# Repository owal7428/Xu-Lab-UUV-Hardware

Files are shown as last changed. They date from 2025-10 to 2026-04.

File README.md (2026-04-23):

# Xu-Lab-UUV-Hardware
Hardware design for Xu Lab underwater modular robotic platform project.

Controller board: <br>
controller

Power board: <br>

power

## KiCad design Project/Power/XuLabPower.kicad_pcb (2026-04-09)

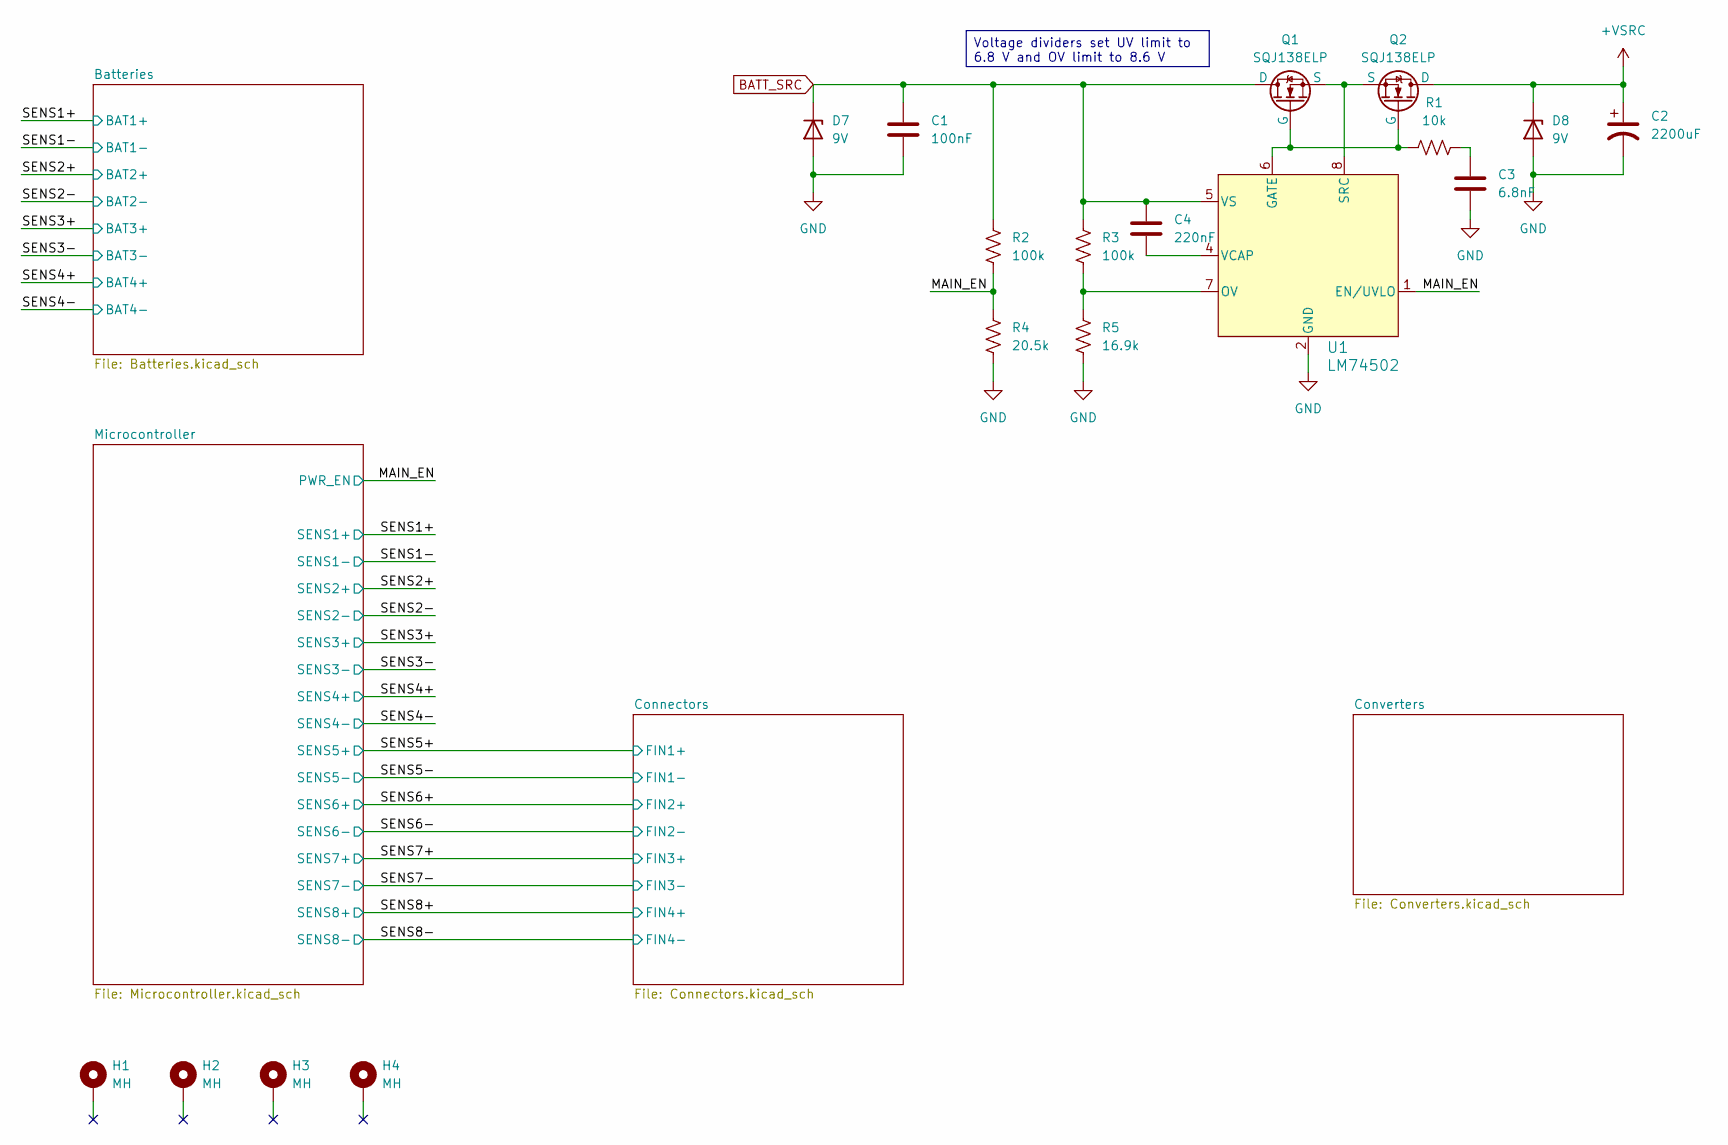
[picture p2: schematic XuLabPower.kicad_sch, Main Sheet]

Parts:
C1: 100nF; C_0603_1608Metric
C2: 2200uF; CP_Radial_D18.0mm_P7.50mm
C3: 6.8nF; C_0603_1608Metric
C4: 220nF; C_0603_1608Metric
D7, D8: 9V; D_SMB
H1, H2, H3, H4: MH; MountingHole_2.7mm_M2.5_Pad_Via
Q1, Q2: SQJ138ELP; PowerPAK_SO-8L
R1: 10k; R_0603_1608Metric
R2, R3: 100k; R_0603_1608Metric
R4: 20.5k; R_0603_1608Metric
R5: 16.9k; R_0603_1608Metric
U1: LM74502; TSOT-23-8

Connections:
+VSRC: C2.1, D8.1 (K), Q2.5 (D); also elsewhere on the board
/MAIN_EN: R2.2, R4.1, U1.1 (EN/UVLO); also elsewhere on the board
BATT_SRC: C1.1, C4.1, D7.1 (K), Q1.5 (D), R2.1, R3.1, U1.5 (VS); also elsewhere on the board
GND: C1.2, C2.2, C3.2, D7.2 (A), D8.2 (A), R4.2, R5.2, U1.2 (GND); also elsewhere on the board
unnamed: C3.1, R1.2
unnamed: Q1.4 (G), Q2.4 (G), R1.1, U1.6 (GATE)
unnamed: R3.2, R5.1, U1.7 (OV)
unnamed: Q1.1 (S), Q1.2 (S), Q1.3 (S), Q2.1 (S), Q2.2 (S), Q2.3 (S), U1.8 (SRC)
unnamed: C4.2, U1.4 (VCAP)

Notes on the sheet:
Voltage dividers set UV limit to 6.8 V and OV limit to 8.6 V

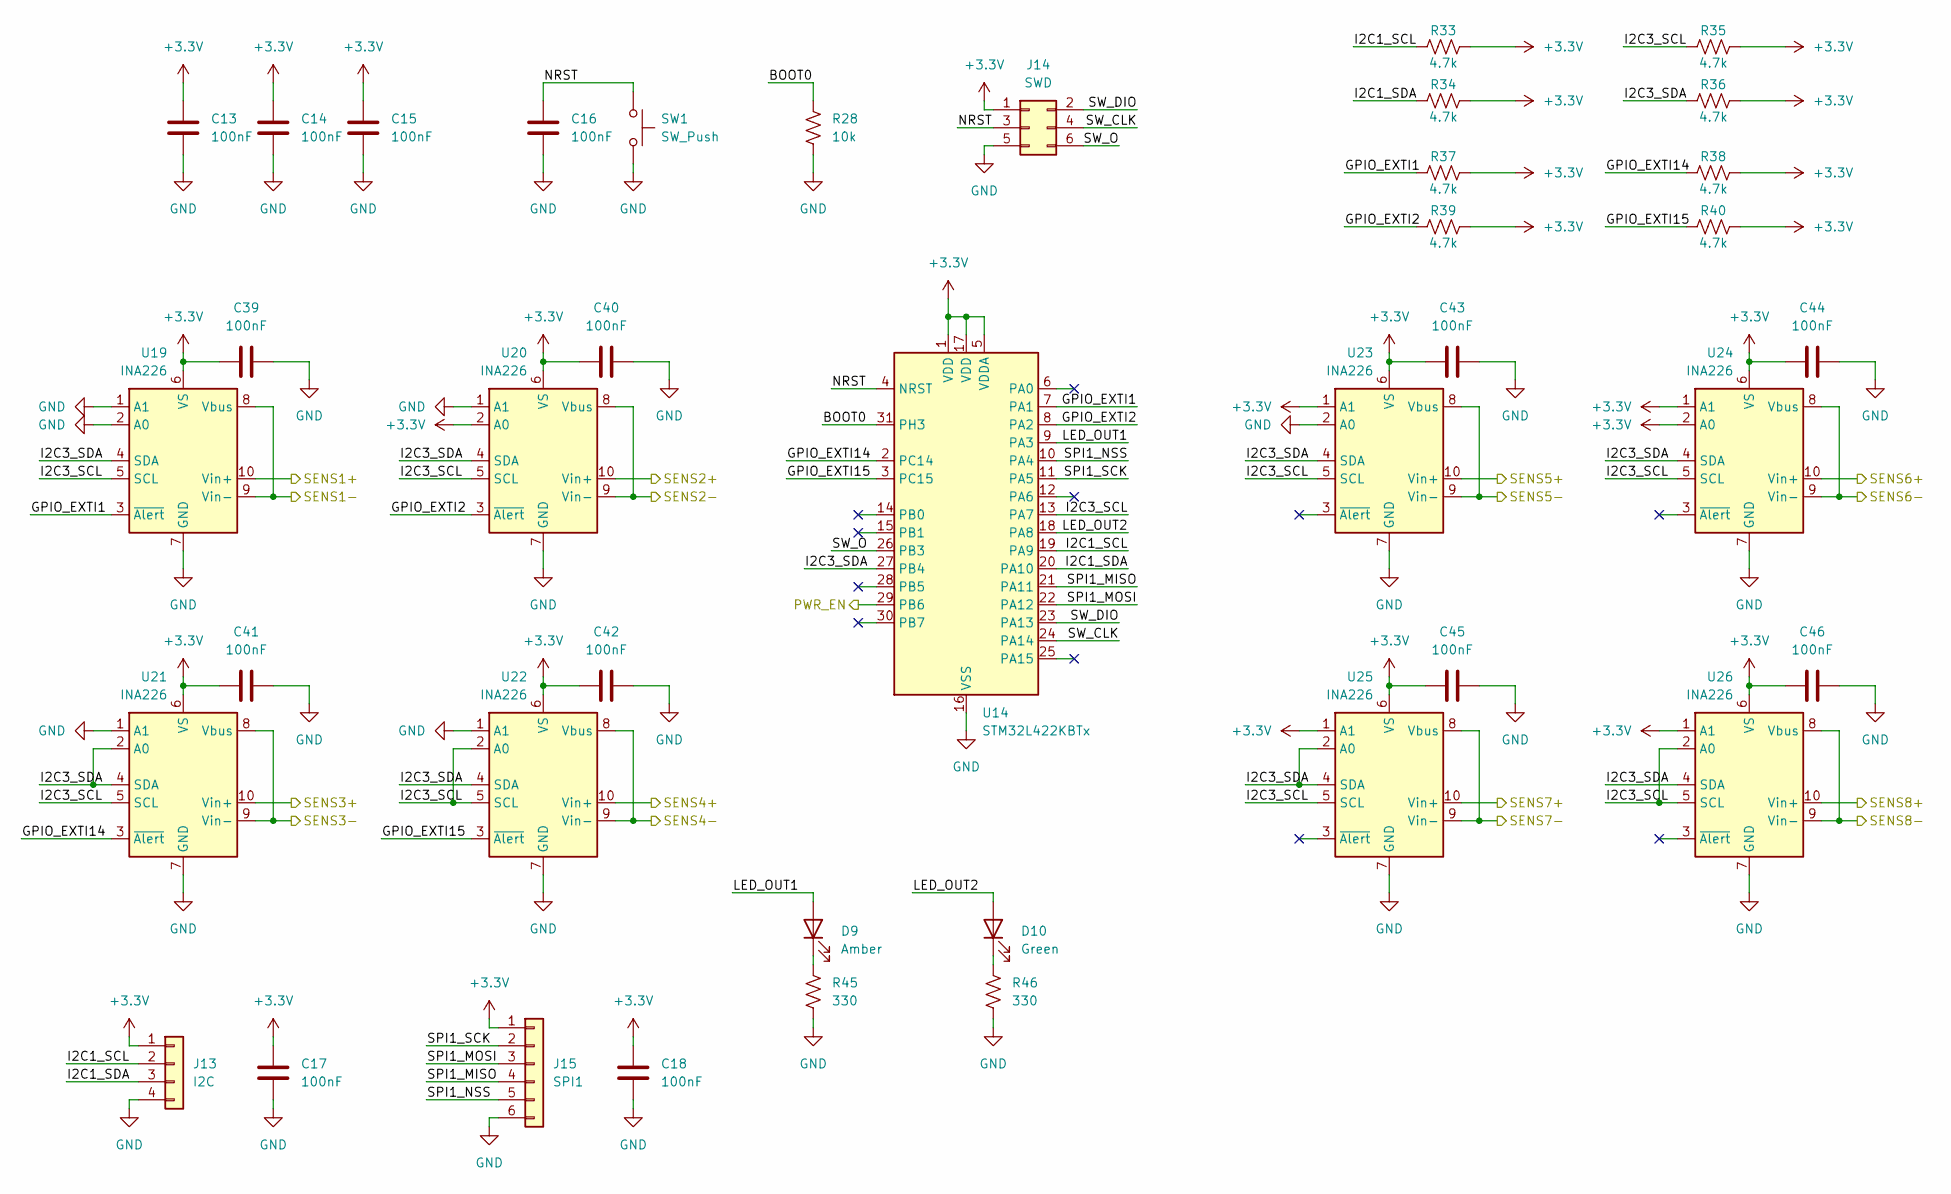
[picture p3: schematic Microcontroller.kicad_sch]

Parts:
C13, C14, C15, C16, C17, C18, C39, C40, C41, C42, C43, C44, C45, C46: 100nF; C_0603_1608Metric
D9: Amber; LED_0603_1608Metric
D10: Green; LED_0603_1608Metric
J13: I2C; JST_GH_SM04B-GHS-TB_1x04-1MP_P1.25mm_Horizontal
J14: SWD; PinHeader_2x03_P2.54mm_Vertical
J15: SPI1; JST_GH_SM06B-GHS-TB_1x06-1MP_P1.25mm_Horizontal
R28: 10k; R_0603_1608Metric
R33, R34, R35, R36, R37, R38, R39, R40: 4.7k; R_0603_1608Metric
R45, R46: 330; R_0603_1608Metric
SW1: SW_Push; SW_Push_1P1T_NO_CK_KMR2
U14: STM32L422KBTx; LQFP-32_7x7mm_P0.8mm
U19, U20, U21, U22, U23, U24, U25, U26: INA226; VSSOP-10_3x3mm_P0.5mm

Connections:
+3.3V: C13.1, C14.1, C15.1, C17.1, C18.1, C39.1, C40.1, C41.1, C42.1, C43.1, C44.1, C45.1, C46.1, J13.1, J14.1, J15.1, R33.1, R34.1, R35.1, R36.1, R37.1, R38.1, R39.1, R40.1, U14.1 (VDD), U14.5 (VDDA), U14.17 (VDD), U19.6 (VS), U20.2 (A0), U20.6 (VS), U21.6 (VS), U22.6 (VS), U23.1 (A1), U23.6 (VS), U24.1 (A1), U24.2 (A0), U24.6 (VS), U25.1 (A1), U25.6 (VS), U26.1 (A1), U26.6 (VS); also elsewhere on the board
+VSRC: U23.10 (Vin+), U24.10 (Vin+), U25.10 (Vin+), U26.10 (Vin+); also elsewhere on the board
/MAIN_EN: U14.29 (PB6); also elsewhere on the board
/Microcontroller/BOOT0: R28.2, U14.31 (PH3)
/Microcontroller/GPIO_EXTI1: R37.2, U14.7 (PA1), U19.3 (~Alert)
/Microcontroller/GPIO_EXTI2: R39.2, U14.8 (PA2), U20.3 (~Alert)
/Microcontroller/GPIO_EXTI14: R38.2, U14.2 (PC14), U21.3 (~Alert)
/Microcontroller/GPIO_EXTI15: R40.2, U14.3 (PC15), U22.3 (~Alert)
/Microcontroller/I2C1_SCL: J13.2, R33.2, U14.19 (PA9)
/Microcontroller/I2C1_SDA: J13.3, R34.2, U14.20 (PA10)
/Microcontroller/I2C3_SCL: R35.2, U14.13 (PA7), U19.5 (SCL), U20.5 (SCL), U21.5 (SCL), U22.2 (A0), U22.5 (SCL), U23.5 (SCL), U24.5 (SCL), U25.5 (SCL), U26.2 (A0), U26.5 (SCL)
/Microcontroller/I2C3_SDA: R36.2, U14.27 (PB4), U19.4 (SDA), U20.4 (SDA), U21.2 (A0), U21.4 (SDA), U22.4 (SDA), U23.4 (SDA), U24.4 (SDA), U25.2 (A0), U25.4 (SDA), U26.4 (SDA)
/Microcontroller/LED_OUT1: D9.2 (A), U14.9 (PA3)
/Microcontroller/LED_OUT2: D10.2 (A), U14.18 (PA8)
/Microcontroller/NRST: C16.1, J14.3, SW1.1, U14.4 (NRST)
/Microcontroller/SPI1_MISO: J15.4, U14.21 (PA11)
/Microcontroller/SPI1_MOSI: J15.3, U14.22 (PA12)
/Microcontroller/SPI1_NSS: J15.5, U14.10 (PA4)
/Microcontroller/SPI1_SCK: J15.2, U14.11 (PA5)
/Microcontroller/SW_CLK: J14.4, U14.24 (PA14)
/Microcontroller/SW_DIO: J14.2, U14.23 (PA13)
/Microcontroller/SW_O: J14.6, U14.26 (PB3)
/SENS1+: U19.10 (Vin+); also elsewhere on the board
/SENS1-: U19.8 (Vbus), U19.9 (Vin-); also elsewhere on the board
/SENS2+: U20.10 (Vin+); also elsewhere on the board
/SENS2-: U20.8 (Vbus), U20.9 (Vin-); also elsewhere on the board
/SENS3+: U21.10 (Vin+); also elsewhere on the board
/SENS3-: U21.8 (Vbus), U21.9 (Vin-); also elsewhere on the board
/SENS4+: U22.10 (Vin+); also elsewhere on the board
/SENS4-: U22.8 (Vbus), U22.9 (Vin-); also elsewhere on the board
/SENS5-: U23.8 (Vbus), U23.9 (Vin-); also elsewhere on the board
/SENS6-: U24.8 (Vbus), U24.9 (Vin-); also elsewhere on the board
/SENS7-: U25.8 (Vbus), U25.9 (Vin-); also elsewhere on the board
/SENS8-: U26.8 (Vbus), U26.9 (Vin-); also elsewhere on the board
GND: C13.2, C14.2, C15.2, C16.2, C17.2, C18.2, C39.2, C40.2, C41.2, C42.2, C43.2, C44.2, C45.2, C46.2, J13.4, J14.5, J15.6, R28.1, R45.2, R46.2, SW1.2, U14.16 (VSS), U14.32 (VSS), U19.1 (A1), U19.2 (A0), U19.7 (GND), U20.1 (A1), U20.7 (GND), U21.1 (A1), U21.7 (GND), U22.1 (A1), U22.7 (GND), U23.2 (A0), U23.7 (GND), U24.7 (GND), U25.7 (GND), U26.7 (GND); also elsewhere on the board
unnamed: D9.1 (K), R45.1
unnamed: D10.1 (K), R46.1

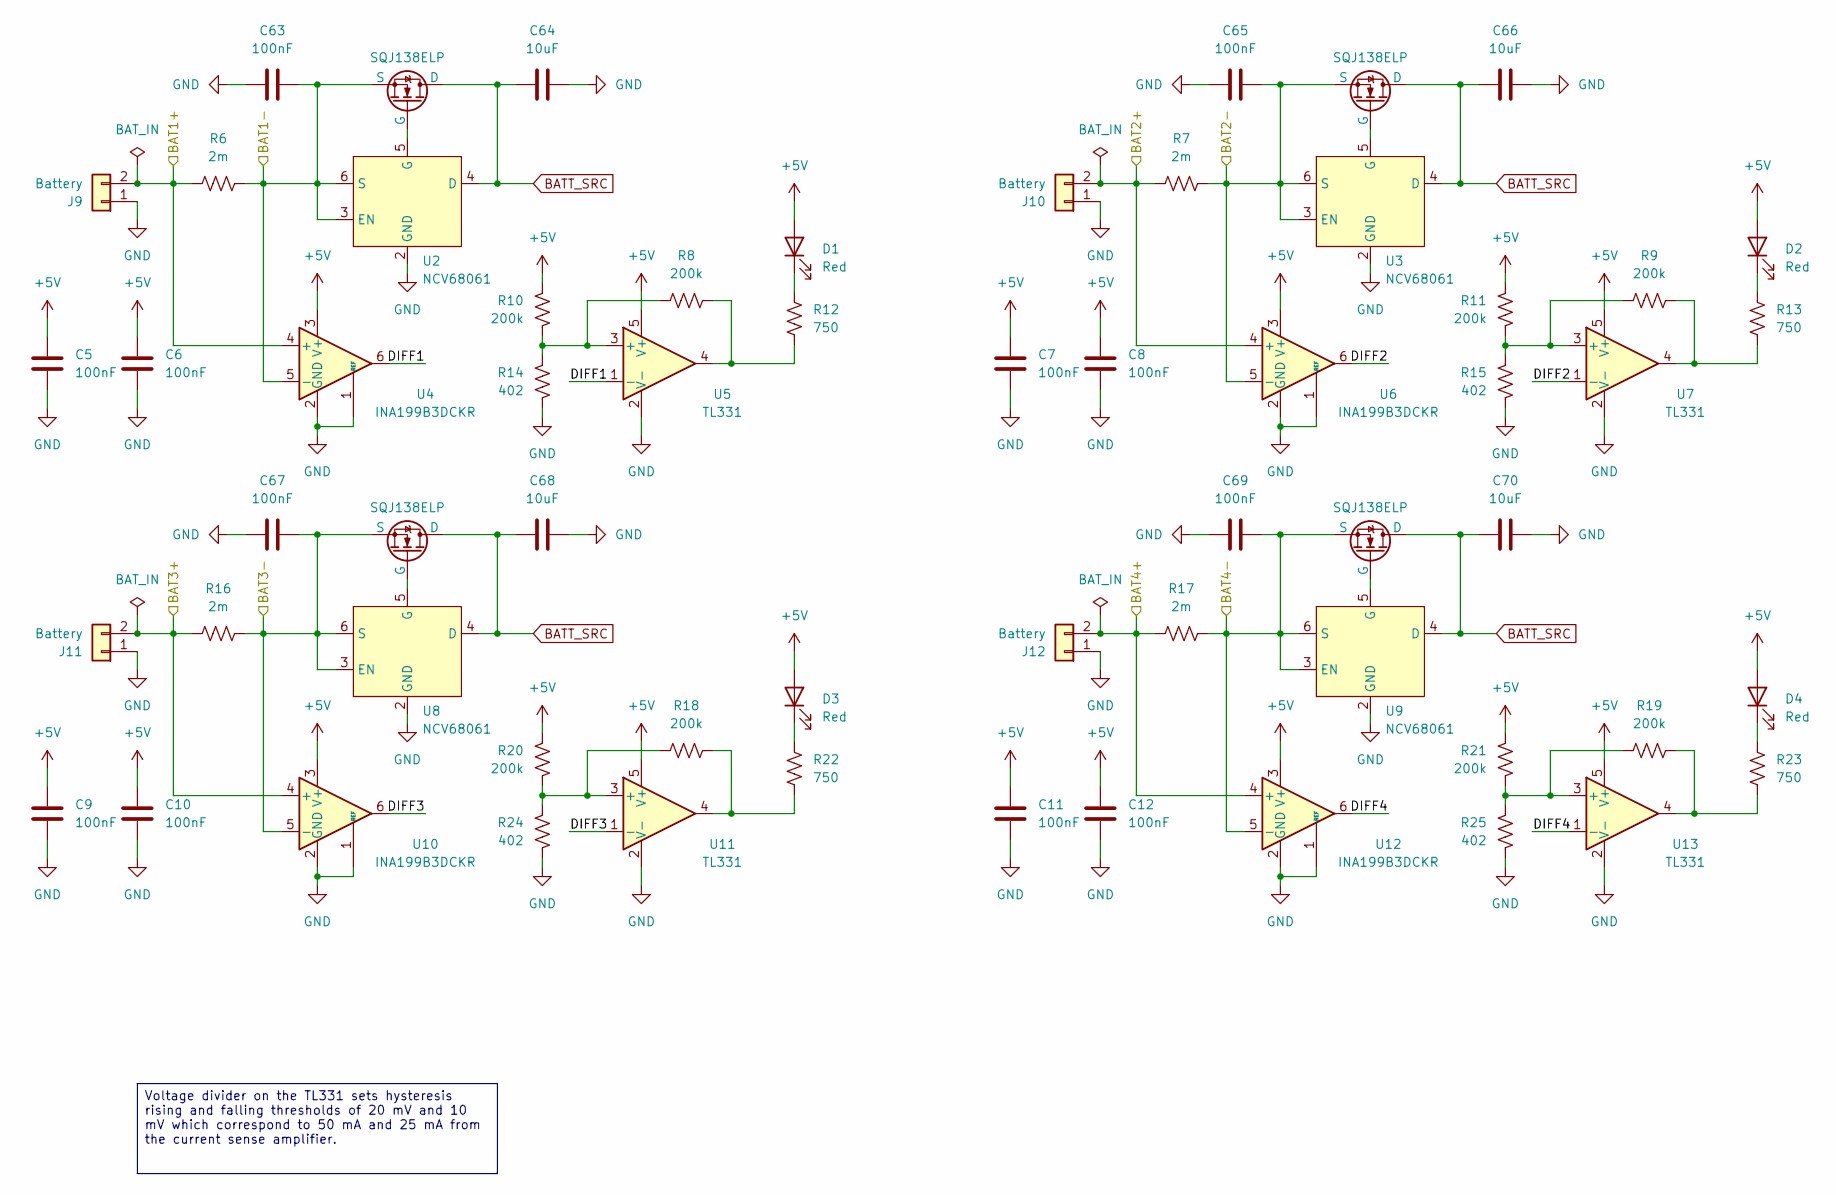
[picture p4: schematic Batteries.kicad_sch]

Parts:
C5, C6, C7, C8, C9, C10, C11, C12, C63, C65, C67, C69: 100nF; C_0603_1608Metric
C64, C66, C68, C70: 10uF; C_1206_3216Metric
D1, D2, D3, D4: Red; LED_0603_1608Metric
J9, J10, J11, J12: Battery; AMASS_XT60-M_1x02_P7.20mm_Vertical
Q3, Q4, Q5, Q6: SQJ138ELP; PowerPAK_SO-8L
R6, R7, R16, R17: 2m; R_2512_6332Metric
R8, R9, R10, R11, R18, R19, R20, R21: 200k; R_0603_1608Metric
R12, R13, R22, R23: 750; R_0603_1608Metric
R14, R15, R24, R25: 402; R_0603_1608Metric
U2, U3, U8, U9: NCV68061; TSOT-23-6
U4, U6, U10, U12: INA199B3DCKR; SOT-363_SC-70-6
U5, U7, U11, U13: TL331; SOT-23-5

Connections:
+5V: C5.1, C6.1, C7.1, C8.1, C9.1, C10.1, C11.1, C12.1, D1.2 (A), D2.2 (A), D3.2 (A), D4.2 (A), R10.1, R11.1, R20.1, R21.1, U4.3 (V+), U5.5 (V+), U6.3 (V+), U7.5 (V+), U10.3 (V+), U11.5 (V+), U12.3 (V+), U13.5 (V+); also elsewhere on the board
/Batteries/DIFF1: U4.6, U5.1 (-)
/Batteries/DIFF2: U6.6, U7.1 (-)
/Batteries/DIFF3: U10.6, U11.1 (-)
/Batteries/DIFF4: U12.6, U13.1 (-)
/SENS1+: J9.2, R6.1, U4.4 (+); also elsewhere on the board
/SENS1-: C63.2, Q3.1 (S), Q3.2 (S), Q3.3 (S), R6.2, U2.3 (EN), U2.6 (S), U4.5 (-); also elsewhere on the board
/SENS2+: J10.2, R7.1, U6.4 (+); also elsewhere on the board
/SENS2-: C65.2, Q4.1 (S), Q4.2 (S), Q4.3 (S), R7.2, U3.3 (EN), U3.6 (S), U6.5 (-); also elsewhere on the board
/SENS3+: J11.2, R16.1, U10.4 (+); also elsewhere on the board
/SENS3-: C67.2, Q5.1 (S), Q5.2 (S), Q5.3 (S), R16.2, U8.3 (EN), U8.6 (S), U10.5 (-); also elsewhere on the board
/SENS4+: J12.2, R17.1, U12.4 (+); also elsewhere on the board
/SENS4-: C69.2, Q6.1 (S), Q6.2 (S), Q6.3 (S), R17.2, U9.3 (EN), U9.6 (S), U12.5 (-); also elsewhere on the board
BATT_SRC: C64.1, C66.1, C68.1, C70.1, Q3.5 (D), Q4.5 (D), Q5.5 (D), Q6.5 (D), U2.4 (D), U3.4 (D), U8.4 (D), U9.4 (D); also elsewhere on the board
GND: C5.2, C6.2, C7.2, C8.2, C9.2, C10.2, C11.2, C12.2, C63.1, C64.2, C65.1, C66.2, C67.1, C68.2, C69.1, C70.2, J9.1, J10.1, J11.1, J12.1, R14.2, R15.2, R24.2, R25.2, U2.1, U2.2 (GND), U3.1, U3.2 (GND), U4.1 (REF), U4.2 (GND), U5.2 (V-), U6.1 (REF), U6.2 (GND), U7.2 (V-), U8.1, U8.2 (GND), U9.1, U9.2 (GND), U10.1 (REF), U10.2 (GND), U11.2 (V-), U12.1 (REF), U12.2 (GND), U13.2 (V-); also elsewhere on the board
unnamed: D1.1 (K), R12.2
unnamed: D2.1 (K), R13.2
unnamed: D3.1 (K), R22.2
unnamed: D4.1 (K), R23.2
unnamed: Q3.4 (G), U2.5 (G)
unnamed: Q4.4 (G), U3.5 (G)
unnamed: Q5.4 (G), U8.5 (G)
unnamed: Q6.4 (G), U9.5 (G)
unnamed: R8.2, R12.1, U5.4
unnamed: R9.2, R13.1, U7.4
unnamed: R18.2, R22.1, U11.4
unnamed: R19.2, R23.1, U13.4
unnamed: R8.1, R10.2, R14.1, U5.3 (+)
unnamed: R9.1, R11.2, R15.1, U7.3 (+)
unnamed: R18.1, R20.2, R24.1, U11.3 (+)
unnamed: R19.1, R21.2, R25.1, U13.3 (+)

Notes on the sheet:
Voltage divider on the TL331 sets hysteresis rising and falling thresholds of 20 mV and 10 mV which correspond to 50 mA and 25 mA from the current sense amplifier.

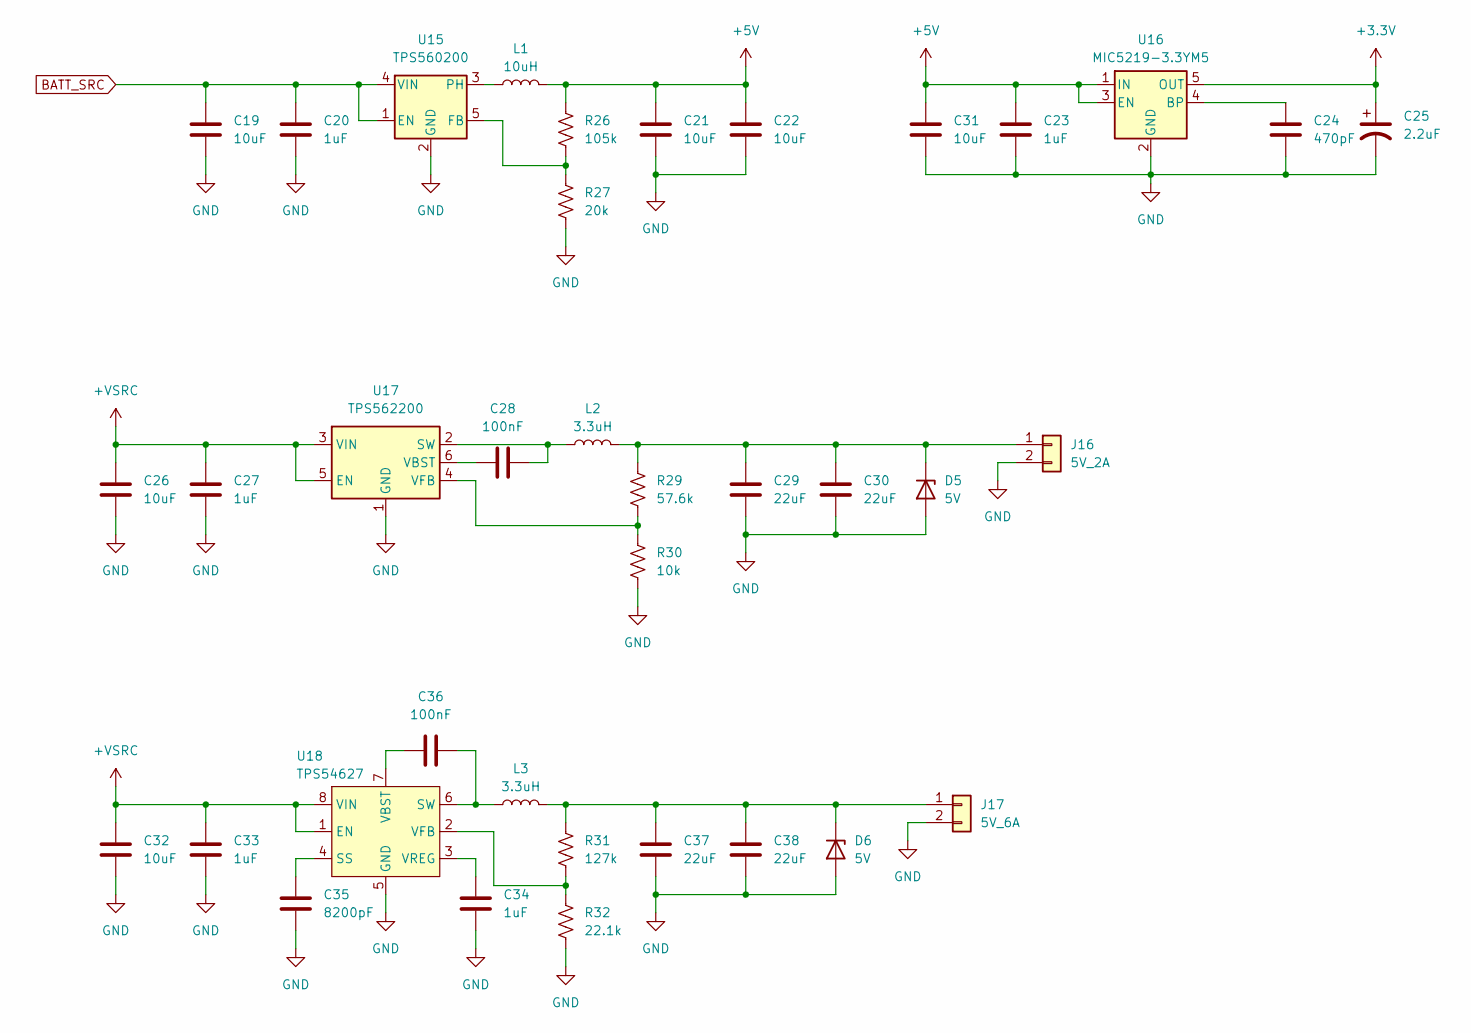
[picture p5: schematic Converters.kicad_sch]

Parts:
C19, C21, C22, C26, C31, C32: 10uF; C_1206_3216Metric
C20, C23, C27, C33, C34: 1uF; C_0603_1608Metric
C24: 470pF; C_0603_1608Metric
C25: 2.2uF; CP_EIA-3216-18_Kemet-A
C28, C36: 100nF; C_0603_1608Metric
C29, C30, C37, C38: 22uF; C_1206_3216Metric
C35: 8200pF; C_0603_1608Metric
D5, D6: 5V; D_MicroSMP_KA
J16: 5V_2A; JST_XH_S2B-XH-A_1x02_P2.50mm_Horizontal
J17: 5V_6A; JST_VH_S2P-VH_1x02_P3.96mm_Horizontal
L1: 10uH; L_1210_3225Metric
L2, L3: 3.3uH; L_APV_APH0630
R26: 105k; R_0603_1608Metric
R27: 20k; R_0603_1608Metric
R29: 57.6k; R_0603_1608Metric
R30: 10k; R_0603_1608Metric
R31: 127k; R_0603_1608Metric
R32: 22.1k; R_0603_1608Metric
U15: TPS560200; SOT-23-5
U16: MIC5219-3.3YM5; SOT-23-5
U17: TPS562200; SOT-23-6
U18: TPS54627; SOIC-8-1EP_3.9x4.9mm_P1.27mm_EP2.95x4.9mm_Mask2.71x3.4mm_Th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

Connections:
+3.3V: C25.1, U16.5 (OUT); also elsewhere on the board
+5V: C21.1, C22.1, C23.1, C31.1, L1.2, R26.1, U16.1 (IN), U16.3 (EN); also elsewhere on the board
+VSRC: C26.1, C27.1, C32.1, C33.1, U17.3 (VIN), U17.5 (EN), U18.1 (EN), U18.8 (VIN); also elsewhere on the board
BATT_SRC: C19.1, C20.1, U15.1 (EN), U15.4 (VIN); also elsewhere on the board
GND: C19.2, C20.2, C21.2, C22.2, C23.2, C24.2, C25.2, C26.2, C27.2, C29.2, C30.2, C31.2, C32.2, C33.2, C34.2, C35.2, C37.2, C38.2, D5.2 (A), D6.2 (A), J16.2, J17.2, R27.2, R30.1, R32.1, U15.2 (GND), U16.2 (GND), U17.1 (GND), U18.5 (GND), U18.9 (GND); also elsewhere on the board
unnamed: C29.1, C30.1, D5.1 (K), J16.1, L2.2, R29.1
unnamed: C37.1, C38.1, D6.1 (K), J17.1, L3.2, R31.1
unnamed: R26.2, R27.1, U15.5 (FB)
unnamed: L1.1, U15.3 (PH)
unnamed: C24.1, U16.4 (BP)
unnamed: C28.2, L2.1, U17.2 (SW)
unnamed: C28.1, U17.6 (VBST)
unnamed: R29.2, R30.2, U17.4 (VFB)
unnamed: C35.1, U18.4 (SS)
unnamed: C36.2, L3.1, U18.6 (SW)
unnamed: C36.1, U18.7 (VBST)
unnamed: R31.2, R32.2, U18.2 (VFB)
unnamed: C34.1, U18.3 (VREG)

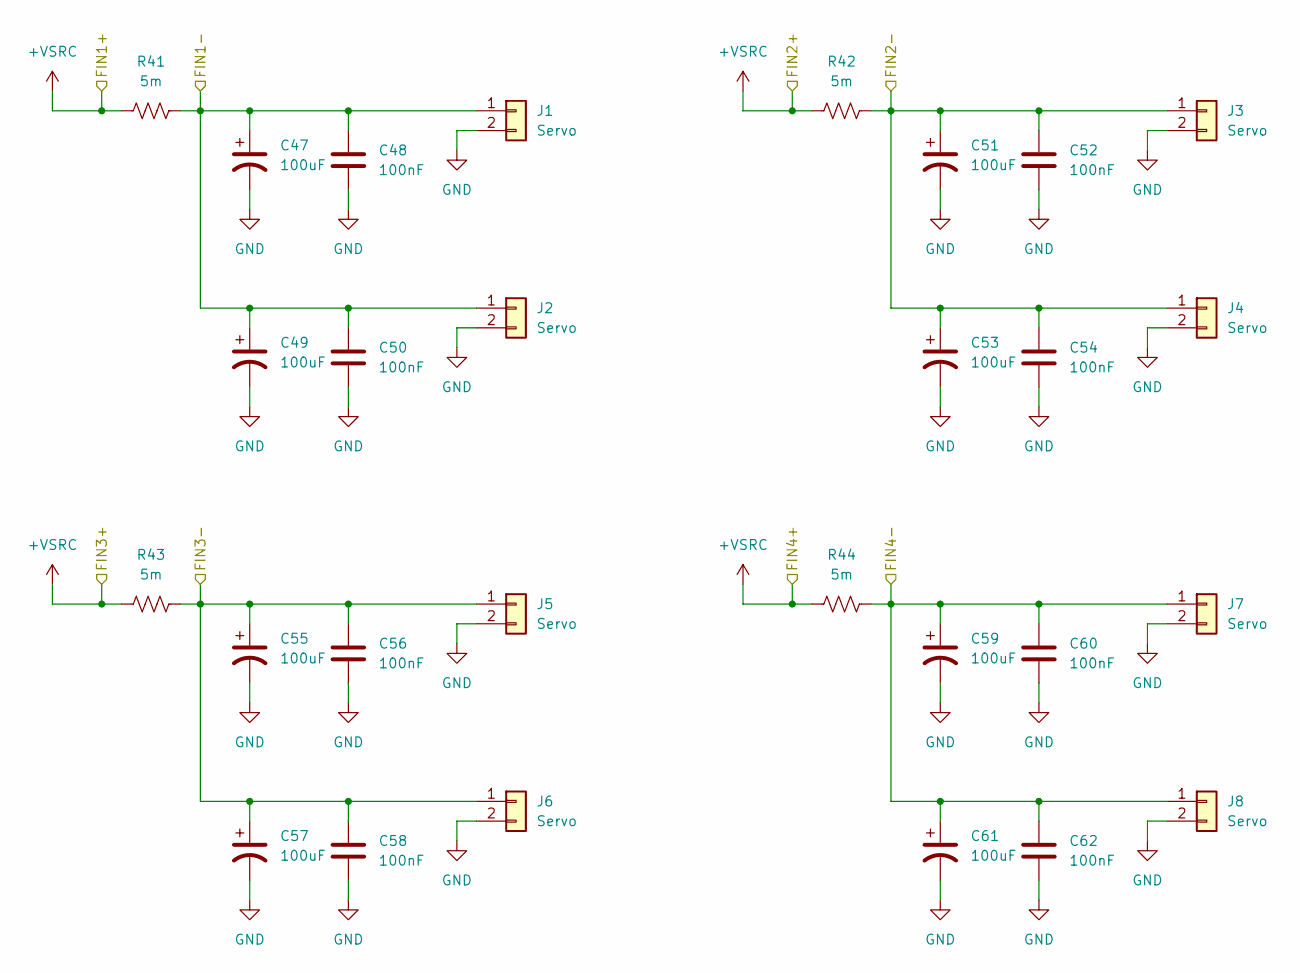
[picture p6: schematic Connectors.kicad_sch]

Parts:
C47, C49, C51, C53, C55, C57, C59, C61: 100uF; CP_Radial_D6.3mm_P2.50mm
C48, C50, C52, C54, C56, C58, C60, C62: 100nF; C_0603_1608Metric
J1, J2, J3, J4, J5, J6, J7, J8: Servo; JST_VH_B2P-VH_1x02_P3.96mm_Vertical
R41, R42, R43, R44: 5m; R_0805_2012Metric

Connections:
+VSRC: R41.1, R42.1, R43.1, R44.1; also elsewhere on the board
/SENS5-: C47.1, C48.1, C49.1, C50.1, J1.1, J2.1, R41.2; also elsewhere on the board
/SENS6-: C51.1, C52.1, C53.1, C54.1, J3.1, J4.1, R42.2; also elsewhere on the board
/SENS7-: C55.1, C56.1, C57.1, C58.1, J5.1, J6.1, R43.2; also elsewhere on the board
/SENS8-: C59.1, C60.1, C61.1, C62.1, J7.1, J8.1, R44.2; also elsewhere on the board
GND: C47.2, C48.2, C49.2, C50.2, C51.2, C52.2, C53.2, C54.2, C55.2, C56.2, C57.2, C58.2, C59.2, C60.2, C61.2, C62.2, J1.2, J2.2, J3.2, J4.2, J5.2, J6.2, J7.2, J8.2; also elsewhere on the board

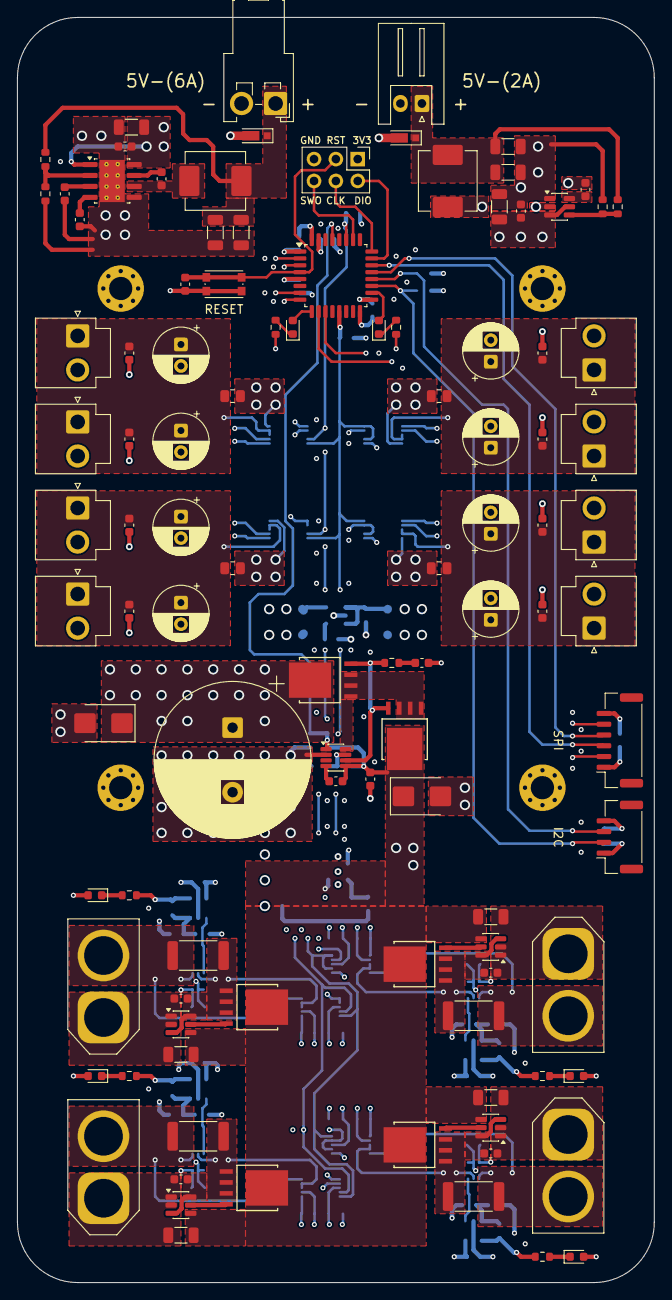
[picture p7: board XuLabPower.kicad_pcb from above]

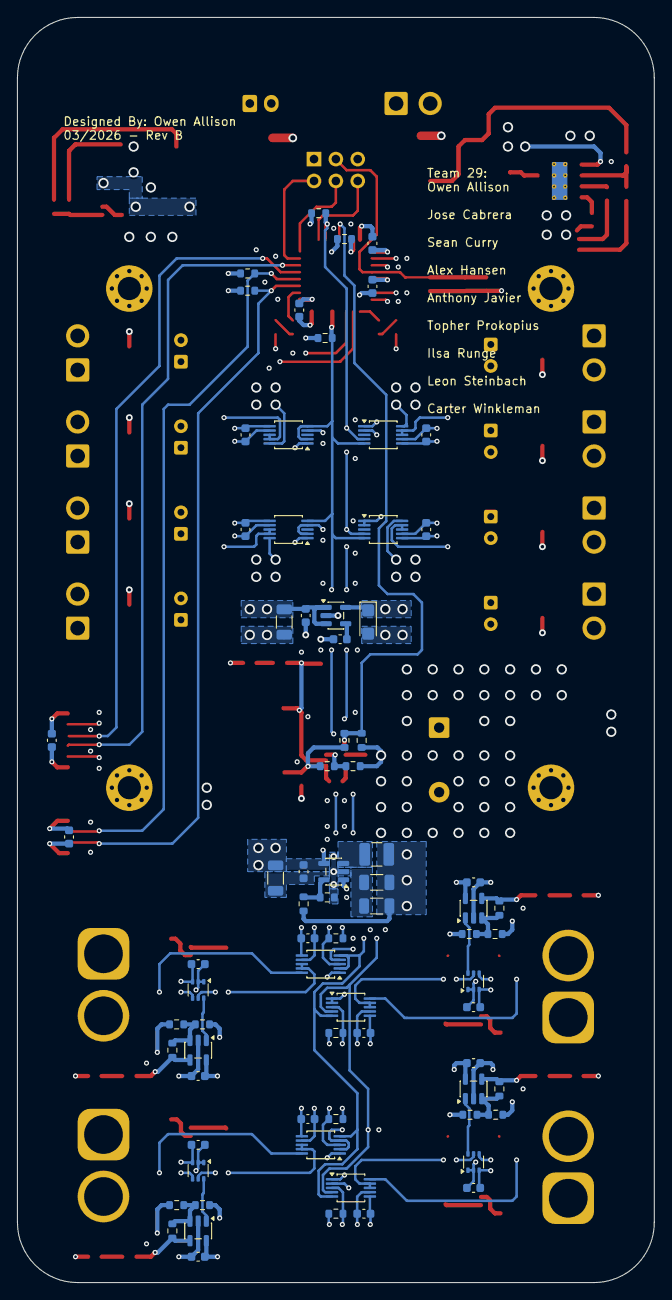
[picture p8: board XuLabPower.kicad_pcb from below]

Board: 8 copper layers, 74.0 x 147.0 mm, 183 parts (75 on the bottom side), 77 nets.

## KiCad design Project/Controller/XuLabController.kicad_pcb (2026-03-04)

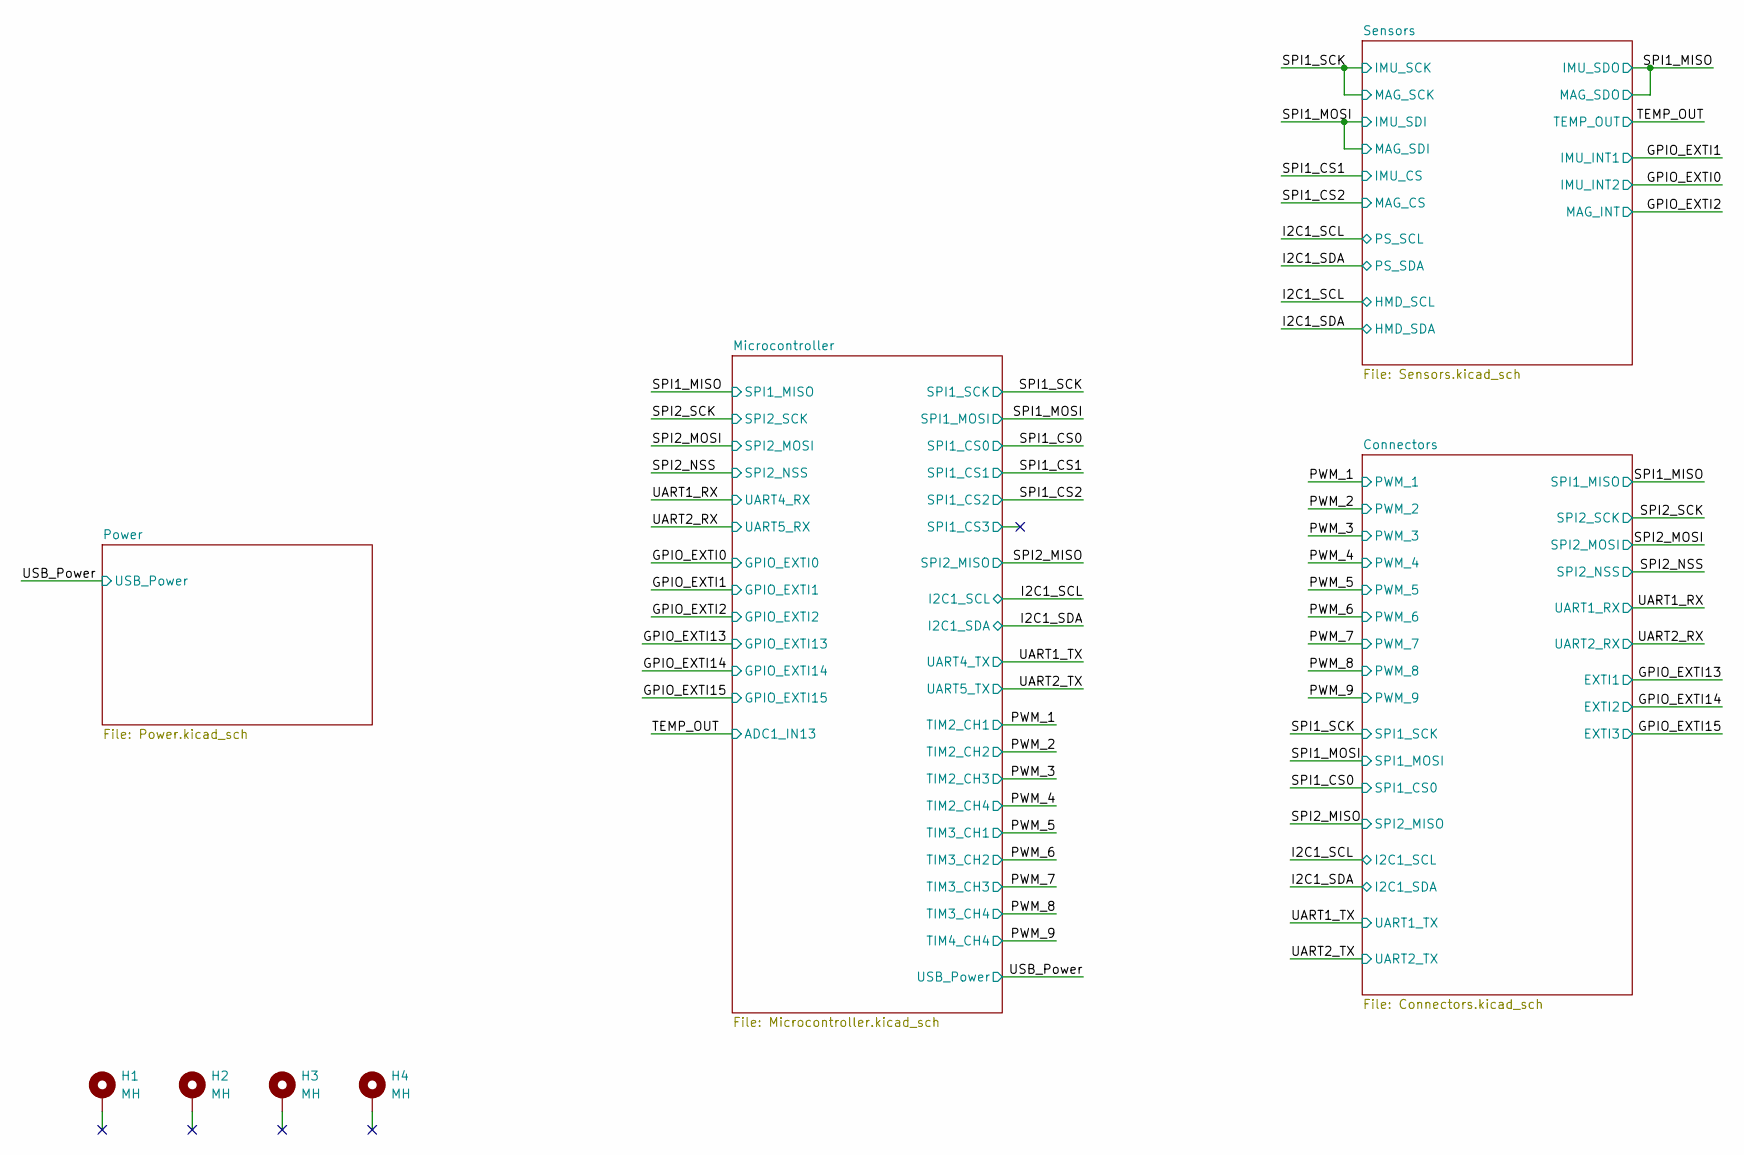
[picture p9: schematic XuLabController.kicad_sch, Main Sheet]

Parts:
H1, H2, H3, H4: MH; MountingHole_2.7mm_M2.5_Pad_Via

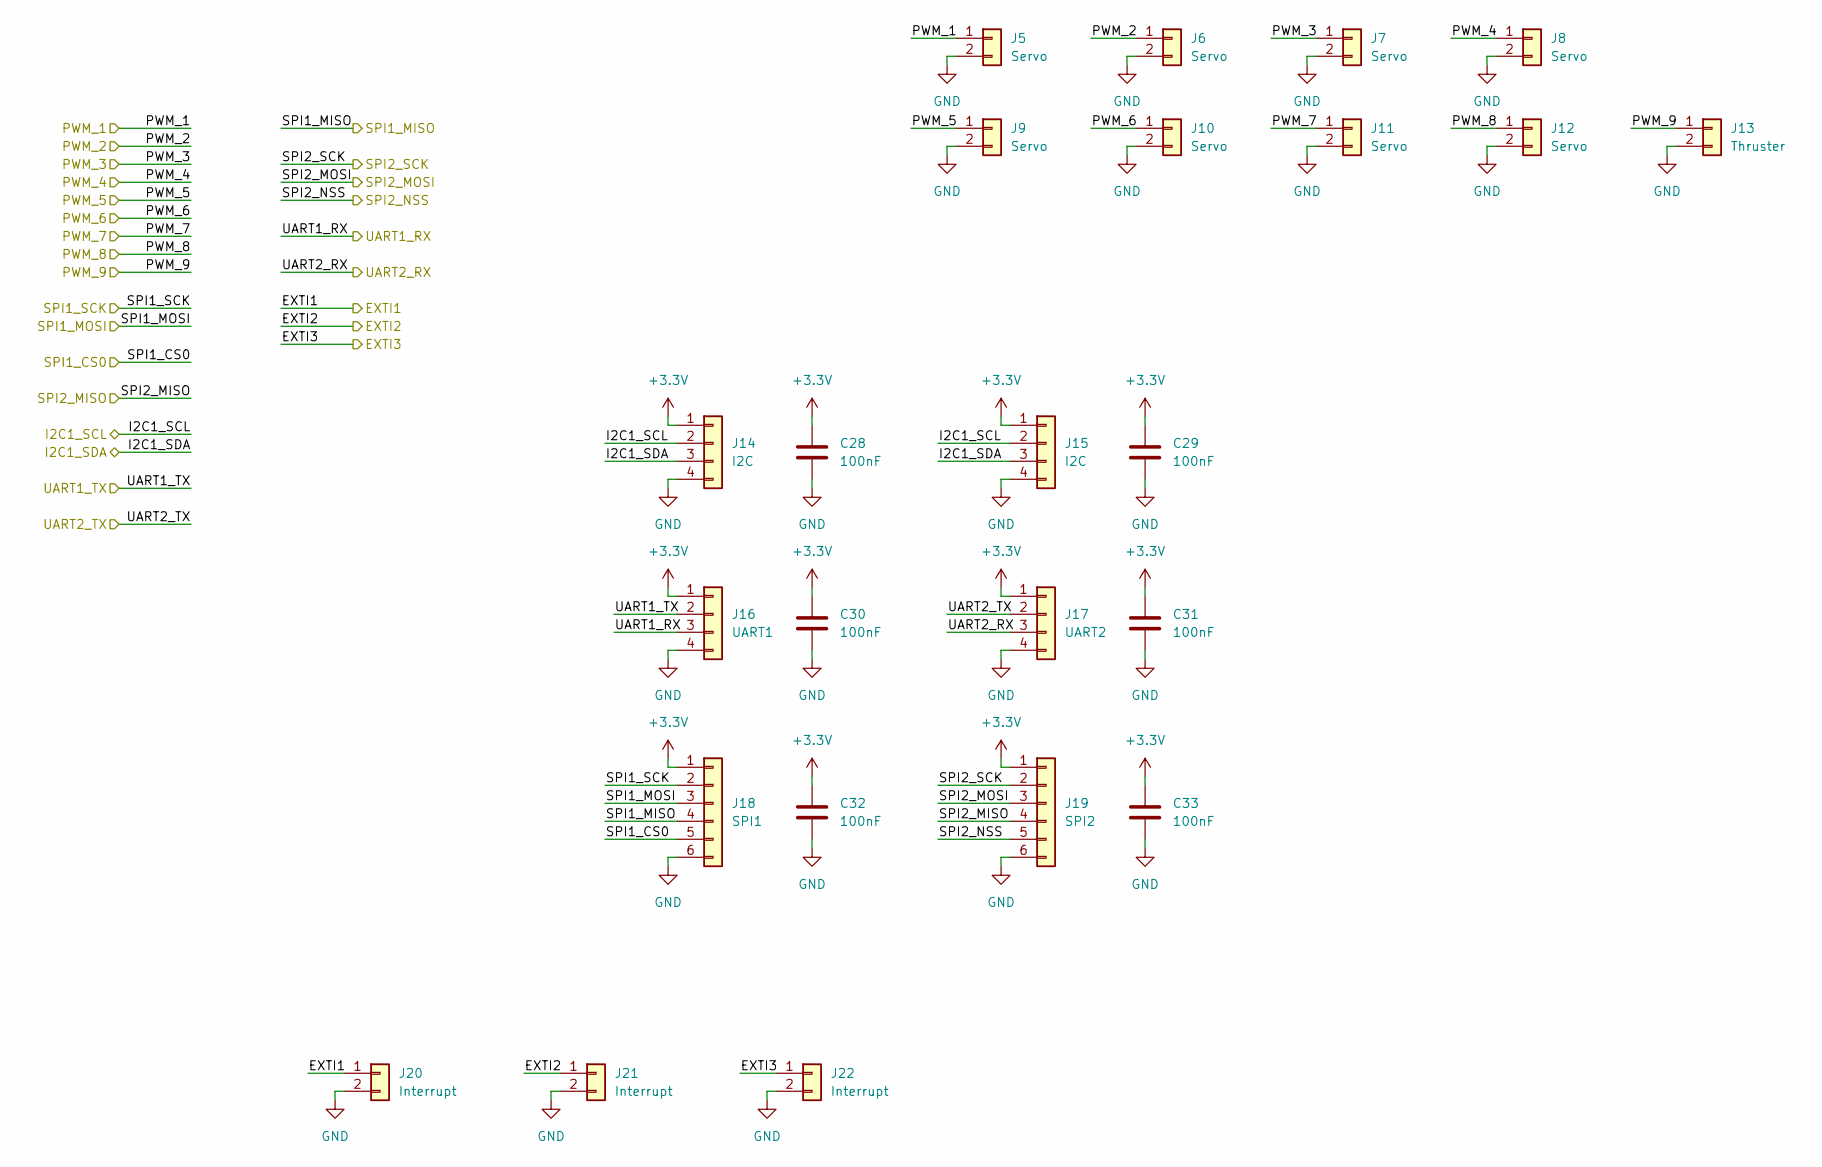
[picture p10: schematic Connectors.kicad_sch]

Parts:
C28, C29, C30, C31, C32, C33: 100nF; C_0603_1608Metric
J5, J6, J7, J8, J9, J10, J11, J12: Servo; JST_VH_B2P-VH_1x02_P3.96mm_Vertical
J13: Thruster; JST_VH_B2P-VH_1x02_P3.96mm_Vertical
J14, J15: I2C; JST_GH_SM04B-GHS-TB_1x04-1MP_P1.25mm_Horizontal
J16: UART1; JST_GH_SM04B-GHS-TB_1x04-1MP_P1.25mm_Horizontal
J17: UART2; JST_GH_SM04B-GHS-TB_1x04-1MP_P1.25mm_Horizontal
J18: SPI1; JST_GH_SM06B-GHS-TB_1x06-1MP_P1.25mm_Horizontal
J19: SPI2; JST_GH_SM06B-GHS-TB_1x06-1MP_P1.25mm_Horizontal
J20, J21, J22: Interrupt; Molex_KK-254_AE-6410-02A_1x02_P2.54mm_Vertical

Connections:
+3.3V: C28.1, C29.1, C30.1, C31.1, C32.1, C33.1, J14.1, J15.1, J16.1, J17.1, J18.1, J19.1; also elsewhere on the board
/GPIO_EXTI13: J20.1; also elsewhere on the board
/GPIO_EXTI14: J21.1; also elsewhere on the board
/GPIO_EXTI15: J22.1; also elsewhere on the board
/I2C1_SCL: J14.2, J15.2; also elsewhere on the board
/I2C1_SDA: J14.3, J15.3; also elsewhere on the board
/PWM_1: J5.1; also elsewhere on the board
/PWM_2: J6.1; also elsewhere on the board
/PWM_3: J7.1; also elsewhere on the board
/PWM_4: J8.1; also elsewhere on the board
/PWM_5: J9.1; also elsewhere on the board
/PWM_6: J10.1; also elsewhere on the board
/PWM_7: J11.1; also elsewhere on the board
/PWM_8: J12.1; also elsewhere on the board
/PWM_9: J13.1; also elsewhere on the board
/SPI1_CS0: J18.5; also elsewhere on the board
/SPI1_MISO: J18.4; also elsewhere on the board
/SPI1_MOSI: J18.3; also elsewhere on the board
/SPI1_SCK: J18.2; also elsewhere on the board
/SPI2_MISO: J19.4; also elsewhere on the board
/SPI2_MOSI: J19.3; also elsewhere on the board
/SPI2_NSS: J19.5; also elsewhere on the board
/SPI2_SCK: J19.2; also elsewhere on the board
/UART1_RX: J16.3; also elsewhere on the board
/UART1_TX: J16.2; also elsewhere on the board
/UART2_RX: J17.3; also elsewhere on the board
/UART2_TX: J17.2; also elsewhere on the board
GND: C28.2, C29.2, C30.2, C31.2, C32.2, C33.2, J5.2, J6.2, J7.2, J8.2, J9.2, J10.2, J11.2, J12.2, J13.2, J14.4, J15.4, J16.4, J17.4, J18.6, J19.6, J20.2, J21.2, J22.2; also elsewhere on the board

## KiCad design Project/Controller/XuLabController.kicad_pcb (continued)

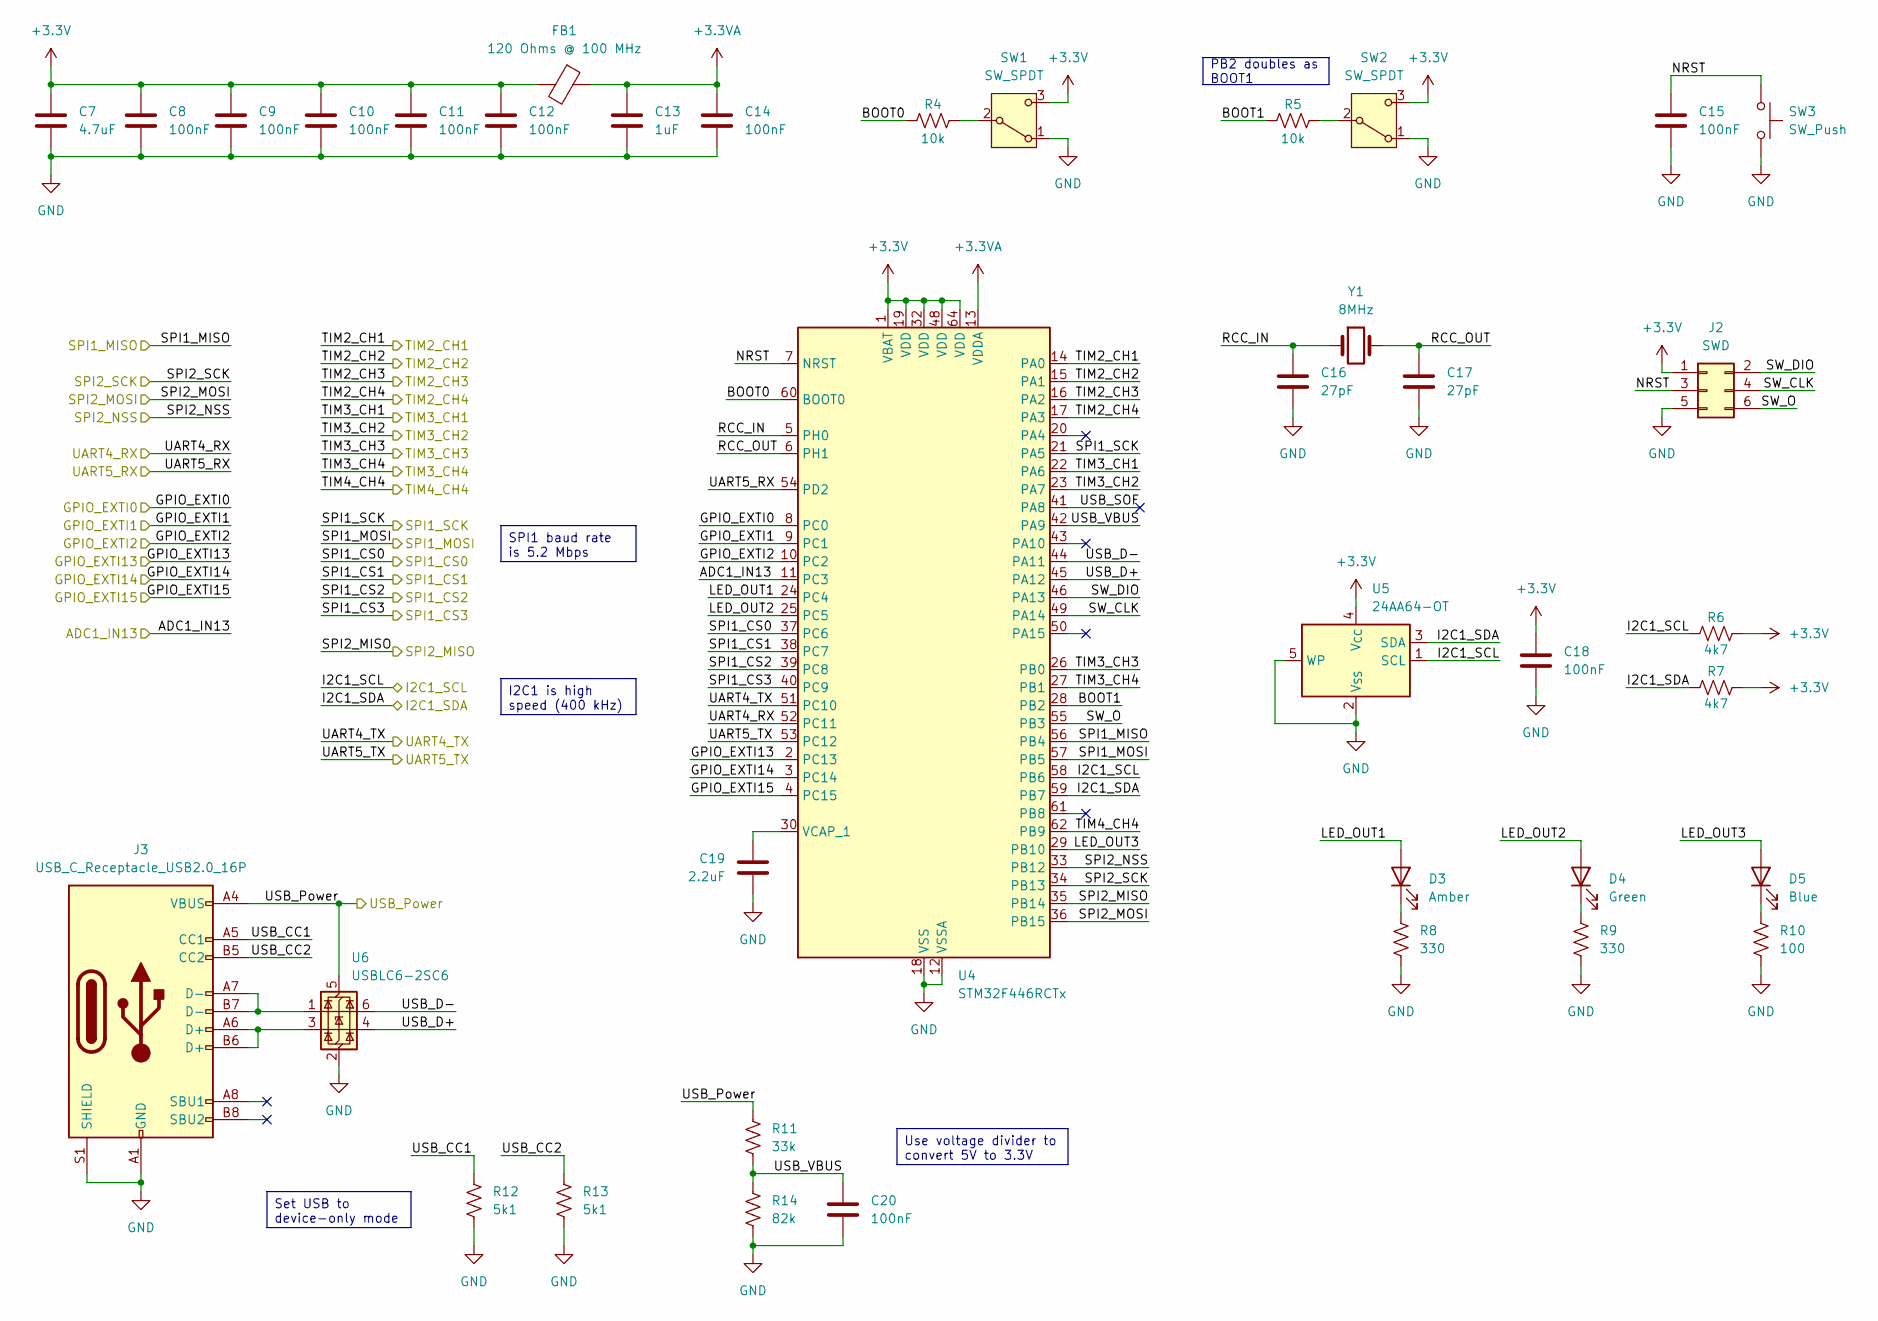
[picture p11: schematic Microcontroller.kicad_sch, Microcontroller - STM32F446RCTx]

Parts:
C7: 4.7uF; C_0603_1608Metric
C8, C9, C10, C11, C12, C14, C15, C18, C20: 100nF; C_0603_1608Metric
C13: 1uF; C_0603_1608Metric
C16, C17: 27pF; C_0603_1608Metric
C19: 2.2uF; C_0603_1608Metric
D3: Amber; LED_0603_1608Metric
D4: Green; LED_0603_1608Metric
D5: Blue; LED_0603_1608Metric
FB1: 120 Ohms @ 100 MHz; L_0805_2012Metric
J2: SWD; PinHeader_2x03_P2.54mm_Vertical
J3: USB_C_Receptacle_USB2.0_16P; USB_C_Receptacle_GCT_USB4105-xx-A_16P_TopMnt_Horizontal
R4, R5: 10k; R_0603_1608Metric
R6, R7: 4k7; R_0603_1608Metric
R8, R9: 330; R_0603_1608Metric
R10: 100; R_0603_1608Metric
R11: 33k; R_0603_1608Metric
R12, R13: 5k1; R_0603_1608Metric
R14: 82k; R_0603_1608Metric
SW1, SW2: SW_SPDT; Nidec_Copal_CAS-120A
SW3: SW_Push; SW_Push_1P1T_NO_CK_KMR2
U4: STM32F446RCTx; LQFP-64_10x10mm_P0.5mm
U5: 24AA64-OT; SOT-23-5
U6: USBLC6-2SC6; SOT-23-6
Y1: 8MHz; Crystal_SMD_Abracon_ABM7-2Pin_6.0x3.5mm

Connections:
+3.3V: C7.1, C8.1, C9.1, C10.1, C11.1, C12.1, C18.1, FB1.2, J2.1, R6.1, R7.1, SW1.3 (C), SW2.3 (C), U4.1 (VBAT), U4.19 (VDD), U4.32 (VDD), U4.48 (VDD), U4.64 (VDD), U5.4 (V_{CC}); also elsewhere on the board
+3.3VA: C13.1, C14.1, FB1.1, U4.13 (VDDA)
/GPIO_EXTI0: U4.8 (PC0); also elsewhere on the board
/GPIO_EXTI1: U4.9 (PC1); also elsewhere on the board
/GPIO_EXTI2: U4.10 (PC2); also elsewhere on the board
/GPIO_EXTI13: U4.2 (PC13); also elsewhere on the board
/GPIO_EXTI14: U4.3 (PC14); also elsewhere on the board
/GPIO_EXTI15: U4.4 (PC15); also elsewhere on the board
/I2C1_SCL: R6.2, U4.58 (PB6), U5.1 (SCL); also elsewhere on the board
/I2C1_SDA: R7.2, U4.59 (PB7), U5.3 (SDA); also elsewhere on the board
/Microcontroller/BOOT0: R4.2, U4.60 (BOOT0)
/Microcontroller/BOOT1: R5.2, U4.28 (PB2)
/Microcontroller/LED_OUT1: D3.2 (A), U4.24 (PC4)
/Microcontroller/LED_OUT2: D4.2 (A), U4.25 (PC5)
/Microcontroller/LED_OUT3: D5.2 (A), U4.29 (PB10)
/Microcontroller/NRST: C15.1, J2.3, SW3.1, U4.7 (NRST)
/Microcontroller/RCC_IN: C16.1, U4.5 (PH0), Y1.1
/Microcontroller/RCC_OUT: C17.1, U4.6 (PH1), Y1.2
/Microcontroller/SPI1_CS3: U4.40 (PC9)
/Microcontroller/SW_CLK: J2.4, U4.49 (PA14)
/Microcontroller/SW_DIO: J2.2, U4.46 (PA13)
/Microcontroller/SW_O: J2.6, U4.55 (PB3)
/Microcontroller/USB_CC1: J3.A5 (CC1), R12.1
/Microcontroller/USB_CC2: J3.B5 (CC2), R13.1
/Microcontroller/USB_D+: U4.45 (PA12), U6.4 (I/O2)
/Microcontroller/USB_D-: U4.44 (PA11), U6.6 (I/O1)
/Microcontroller/USB_SOF: U4.41 (PA8)
/Microcontroller/USB_VBUS: C20.1, R11.2, R14.1, U4.42 (PA9)
/PWM_1: U4.14 (PA0); also elsewhere on the board
/PWM_2: U4.15 (PA1); also elsewhere on the board
/PWM_3: U4.16 (PA2); also elsewhere on the board
/PWM_4: U4.17 (PA3); also elsewhere on the board
/PWM_5: U4.22 (PA6); also elsewhere on the board
/PWM_6: U4.23 (PA7); also elsewhere on the board
/PWM_7: U4.26 (PB0); also elsewhere on the board
/PWM_8: U4.27 (PB1); also elsewhere on the board
/PWM_9: U4.62 (PB9); also elsewhere on the board
/SPI1_CS0: U4.37 (PC6); also elsewhere on the board
/SPI1_CS1: U4.38 (PC7); also elsewhere on the board
/SPI1_CS2: U4.39 (PC8); also elsewhere on the board
/SPI1_MISO: U4.56 (PB4); also elsewhere on the board
/SPI1_MOSI: U4.57 (PB5); also elsewhere on the board
/SPI1_SCK: U4.21 (PA5); also elsewhere on the board
/SPI2_MISO: U4.35 (PB14); also elsewhere on the board
/SPI2_MOSI: U4.36 (PB15); also elsewhere on the board
/SPI2_NSS: U4.33 (PB12); also elsewhere on the board
/SPI2_SCK: U4.34 (PB13); also elsewhere on the board
/TEMP_OUT: U4.11 (PC3); also elsewhere on the board
/UART1_RX: U4.52 (PC11); also elsewhere on the board
/UART1_TX: U4.51 (PC10); also elsewhere on the board
/UART2_RX: U4.54 (PD2); also elsewhere on the board
/UART2_TX: U4.53 (PC12); also elsewhere on the board
/USB_Power: J3.A4 (VBUS), J3.A9 (VBUS), J3.B4 (VBUS), J3.B9 (VBUS), R11.1, U6.5 (VBUS); also elsewhere on the board
GND: C7.2, C8.2, C9.2, C10.2, C11.2, C12.2, C13.2, C14.2, C15.2, C16.2, C17.2, C18.2, C19.2, C20.2, J2.5, J3.A1 (GND), J3.A12 (GND), J3.B1 (GND), J3.B12 (GND), J3.S1 (SHIELD), R8.2, R9.2, R10.2, R12.2, R13.2, R14.2, SW1.1 (A), SW2.1 (A), SW3.2, U4.12 (VSSA), U4.18 (VSS), U4.31 (VSS), U4.47 (VSS), U4.63 (VSS), U5.2 (V_{SS}), U5.5 (WP), U6.2 (GND); also elsewhere on the board
unnamed: D3.1 (K), R8.1
unnamed: D4.1 (K), R9.1
unnamed: D5.1 (K), R10.1
unnamed: J3.A6 (D+), J3.B6 (D+), U6.3 (I/O2)
unnamed: J3.A7 (D-), J3.B7 (D-), U6.1 (I/O1)
unnamed: R4.1, SW1.2 (B)
unnamed: R5.1, SW2.2 (B)
unnamed: C19.1, U4.30 (VCAP_1)

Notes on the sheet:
Use voltage divider to convert 5V to 3.3V
I2C1 is high speed (400 kHz)
Set USB to device-only mode
SPI1 baud rate is 5.2 Mbps
PB2 doubles as BOOT1

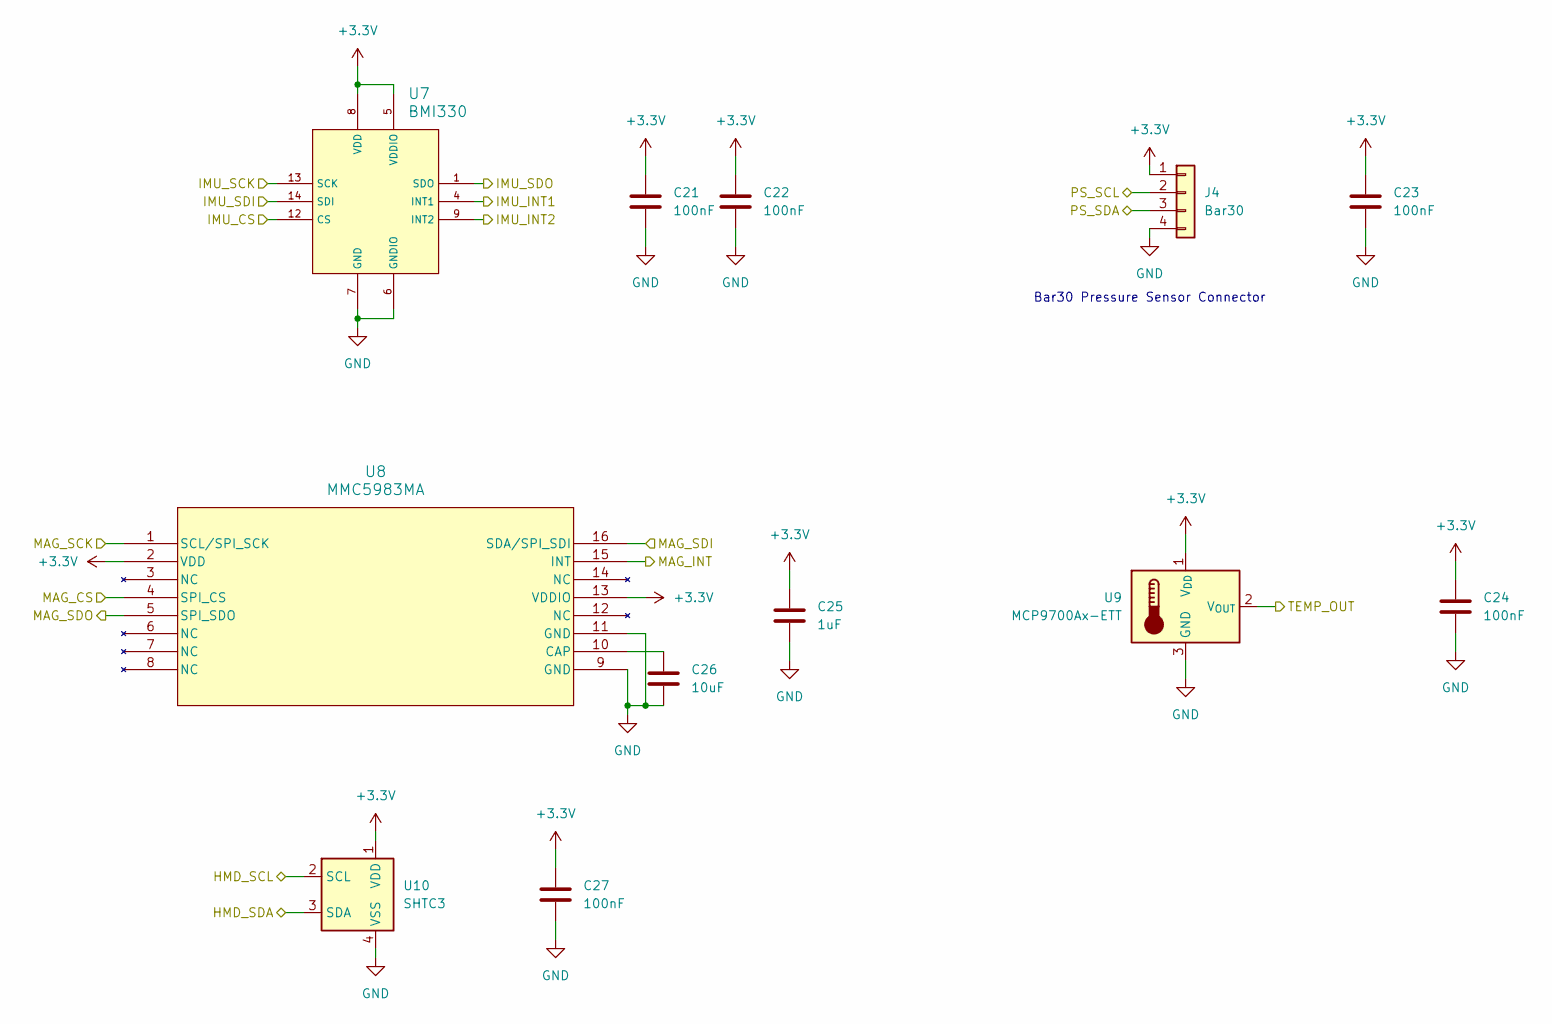
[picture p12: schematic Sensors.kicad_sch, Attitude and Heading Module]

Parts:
C21, C22, C23, C24, C27: 100nF; C_0603_1608Metric
C25: 1uF; C_0603_1608Metric
C26: 10uF; C_1206_3216Metric
J4: Bar30; JST_GH_SM04B-GHS-TB_1x04-1MP_P1.25mm_Horizontal
U7: BMI330
U8: MMC5983MA; MMC5983MA_MEM
U9: MCP9700Ax-ETT; SOT-23
U10: SHTC3; Sensirion_DFN-4-1EP_2x2mm_P1mm_EP0.7x1.6mm

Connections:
+3.3V: C21.1, C22.1, C23.1, C24.1, C25.1, C27.1, J4.1, U7.5 (VDDIO), U7.8 (VDD), U8.2 (VDD), U8.13 (VDDIO), U9.1 (V_{DD}), U10.1 (VDD); also elsewhere on the board
/GPIO_EXTI0: U7.9 (INT2); also elsewhere on the board
/GPIO_EXTI1: U7.4 (INT1); also elsewhere on the board
/GPIO_EXTI2: U8.15 (INT); also elsewhere on the board
/I2C1_SCL: J4.2, U10.2 (SCL); also elsewhere on the board
/I2C1_SDA: J4.3, U10.3 (SDA); also elsewhere on the board
/SPI1_CS1: U7.12 (CS); also elsewhere on the board
/SPI1_CS2: U8.4 (SPI_CS); also elsewhere on the board
/SPI1_MISO: U7.1 (SDO), U8.5 (SPI_SDO); also elsewhere on the board
/SPI1_MOSI: U7.14 (SDI), U8.16 (SDA/SPI_SDI); also elsewhere on the board
/SPI1_SCK: U7.13 (SCK), U8.1 (SCL/SPI_SCK); also elsewhere on the board
/TEMP_OUT: U9.2 (V_{OUT}); also elsewhere on the board
GND: C21.2, C22.2, C23.2, C24.2, C25.2, C26.2, C27.2, J4.4, U7.6 (GNDIO), U7.7 (GND), U8.9 (GND), U8.11 (GND), U9.3 (GND), U10.4 (VSS); also elsewhere on the board
unnamed: C26.1, U8.10 (CAP)

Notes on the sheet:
Bar30 Pressure Sensor Connector

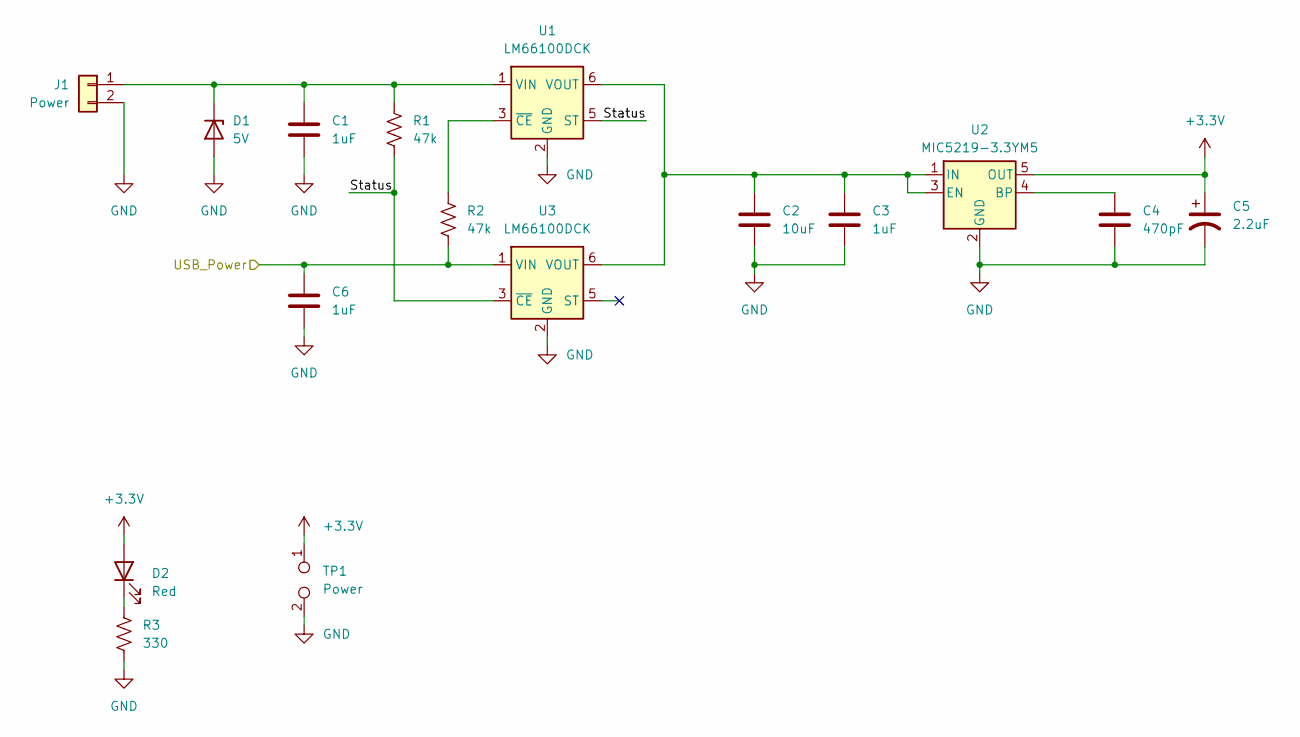
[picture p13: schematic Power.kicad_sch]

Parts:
C1, C3, C6: 1uF; C_0603_1608Metric
C2: 10uF; C_1206_3216Metric
C4: 470pF; C_0603_1608Metric
C5: 2.2uF; CP_EIA-3216-18_Kemet-A
D1: 5V; D_PowerDI-123
D2: Red; LED_0603_1608Metric
J1: Power; JST_GH_SM02B-GHS-TB_1x02-1MP_P1.25mm_Horizontal
R1, R2: 47k; R_0603_1608Metric
R3: 330; R_0603_1608Metric
TP1: Power; TestPoint_2Pads_Pitch2.54mm_Drill0.8mm
U1, U3: LM66100DCK; SOT-363_SC-70-6
U2: MIC5219-3.3YM5; SOT-23-5

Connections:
+3.3V: C5.1, D2.2 (A), TP1.1, U2.5 (OUT); also elsewhere on the board
/Power/Status: R1.2, U1.5 (ST), U3.3 (~CE)
/USB_Power: C6.1, R2.2, U3.1 (VIN); also elsewhere on the board
GND: C1.2, C2.2, C3.2, C4.2, C5.2, C6.2, D1.2 (A), J1.2, R3.2, TP1.2, U1.2 (GND), U2.2 (GND), U3.2 (GND); also elsewhere on the board
unnamed: C1.1, D1.1 (K), J1.1, R1.1, U1.1 (VIN)
unnamed: D2.1 (K), R3.1
unnamed: C2.1, C3.1, U1.6 (VOUT), U2.1 (IN), U2.3 (EN), U3.6 (VOUT)
unnamed: R2.1, U1.3 (~CE)
unnamed: C4.1, U2.4 (BP)



Board: 4 copper layers, 75.0 x 81.0 mm, 94 parts (28 on the bottom side), 67 nets.

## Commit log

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2025-10-04 Add initial project files
    [xu_lab_platform.kicad_pcb, xu_lab_platform.kicad_sch]
2025-10-07 Add schematic files for MCUA
    [xu_lab_platform.kicad_sch, xu_lab_platform_mcu1.kicad_sch]
2025-10-07 Connect power pins and add decoupling capacitors
    [xu_lab_platform_mcu1.kicad_sch]
2025-10-09 Add circuits to configure reset and boot pins
    [xu_lab_platform_mcu1.kicad_sch]
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2025-10-15 Add external crystal oscillator
    [xu_lab_platform_mcu1.kicad_sch]
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2025-10-15 Add pull up resistors for I2C pins
    [xu_lab_platform_mcu1.kicad_sch]
2025-10-15 Add hierarchical pins for MCU A and update main sheet
    [xu_lab_platform.kicad_sch, xu_lab_platform_mcu1.kicad_sch]
2025-10-16 Add hierarchical sheet for attitude and heading sensors
    [xu_lab_platform.kicad_sch, xu_lab_platform_ahrs.kicad_sch]
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2025-10-16 Add 9DoF IMU and magnetometer sensors to sheet
    [xu_lab_platform_ahrs.kicad_sch]
2025-10-17 Update MCU A pin configuration with SPI CS and an LED output
    [xu_lab_platform.kicad_sch, xu_lab_platform_mcu1.kicad_sch]
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2025-10-21 Add pressure sensor schematic
    [xu_lab_platform.kicad_sch, xu_lab_platform_ahrs.kicad_sch]
2025-10-21 Connect MCU A to sensors
    [xu_lab_platform.kicad_sch, xu_lab_platform_mcu1.kicad_sch]
2025-10-22 Rename files using pascal case and update references
    [AttitudeHeadingModule.kicad_sch, MicrocontrollerA.kicad_sch, XuLabPlatform.kicad_pcb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]
2025-10-23 Change IMU to ISM330DHCX and remove SPI level converter
    [AttitudeHeadingModule.kicad_sch]
2025-10-23 Change magnetometer to MMC5983MA
    [AttitudeHeadingModule.kicad_sch]
2025-10-24 Change magnetometer interface from I2C to SPI
    [AttitudeHeadingModule.kicad_sch, MicrocontrollerA.kicad_sch, XuLabPlatform.kicad_sch]
2025-10-24 Add power schematic sheet
    [Power.kicad_sch, XuLabPlatform.kicad_sch]
2025-10-27 Add screw terminal power input and symbol
    [Power.kicad_sch]
2025-10-27 Add 3v3 buck converter
    [Power.kicad_sch]
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2025-10-27 Add connectors for servo power
    [Power.kicad_sch]
2025-10-27 Add indicator LED for MCU A
    [MicrocontrollerA.kicad_sch, XuLabPlatform.kicad_sch]
2025-10-27 Add signal outputs for servos and change screw terminal footprints
    [Power.kicad_sch, XuLabPlatform.kicad_sch]
2025-10-27 Increase power rail decoupling capacitor values
    [Power.kicad_sch]
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2025-10-30 Fix duplicate capacitor labels
    [AttitudeHeadingModule.kicad_sch, Power.kicad_sch]
2025-10-31 Add thruster pin outputs
    [MicrocontrollerA.kicad_sch, XuLabPlatform.kicad_sch]
2025-11-02 Combine servo outputs to 3 pin terminal
    [Power.kicad_sch, XuLabPlatform.kicad_sch]
2025-11-02 Remove unused I2C pins and add USB
    [MicrocontrollerA.kicad_sch, XuLabPlatform.kicad_sch]
2025-11-02 Add footprints to symbols
    [AttitudeHeadingModule.kicad_sch, MicrocontrollerA.kicad_sch, Power.kicad_sch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]
2025-11-03 Make USB lines differential
    [MicrocontrollerA.kicad_sch]
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2025-11-03 Add surge protection for USB VBUS line
    [MicrocontrollerA.kicad_sch]
2025-11-03 Add info for pcb sheet
    [XuLabPlatform.kicad_pcb]
2025-11-03 Fix missing net label for SPI1 SCK
    [MicrocontrollerA.kicad_sch, XuLabPlatform.kicad_sch]
2025-11-03 Switch from variable to fixed 3.3V buck converter
    [MicrocontrollerA.kicad_sch, Power.kicad_sch]
2025-11-13 Add initial PCB layout
    [XuLabPlatform.kicad_pcb]
2025-11-13 Change ferrite bead with TLV1117LV33 LDO for 3.3VA filtering
    [MicrocontrollerA.kicad_sch, XuLabPlatform.kicad_pcb]
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2025-11-14 Replace Schottky diode with P-channel mosfet circuit
    [Power.kicad_sch, XuLabPlatform.kicad_pcb]
2025-11-14 Add breakout sockets for microcontroller IO lines
    [XuLabPlatform.kicad_pcb, XuLabPlatform.kicad_sch]
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2025-11-19 Add ground plane and crystal connections
    [XuLabPlatform.kicad_pcb]
2025-11-19 Add rest of connections
    [AttitudeHeadingModule.kicad_sch, MicrocontrollerA.kicad_sch, XuLabPlatform.kicad_pcb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]
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2025-11-27 Replace zener diode footprints with generics
    [MicrocontrollerA.kicad_sch, Power.kicad_sch, XuLabPlatform.kicad_pcb]
2025-12-04 Add ferrite bead and decoupling capacitors to analog power input
    [MicrocontrollerA.kicad_sch, XuLabPlatform.kicad_pcb]
2025-12-04 Add 3.3 V voltage divider to 5 V VBUS line
    [MicrocontrollerA.kicad_sch, XuLabPlatform.kicad_pcb]
2025-12-17 Remove LDO and connect FB to switching output
    [MicrocontrollerA.kicad_sch, XuLabPlatform.kicad_pcb]
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2026-01-23 Change servo connectors from screw to JST B3P-VH
    [XuLabPlatform.kicad_sch]
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2026-01-26 Change output peripheral output connectors to Molex PicoBlade
    [XuLabPlatform.kicad_sch]
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2026-01-28 Replace EXTI3 with EXTI0
    [MicrocontrollerA.kicad_sch, XuLabPlatform.kicad_sch]
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2026-02-05 Add LDO to power input for controller board
    [Connectors.kicad_sch, Microcontroller.kicad_sch, Sensors.kicad_sch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]
2026-02-05 Change USB connector from USB-B Micro to USB-C
    [Connectors.kicad_sch, Microcontroller.kicad_sch, Sensors.kicad_sch]
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2026-03-02 Add ideal diode ORing for power connector and USB power
    [Connectors.kicad_sch, Microcontroller.kicad_sch, Power.kicad_sch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]
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2026-03-02 Add two more LEDs and increase LED series resistance
    [Microcontroller.kicad_sch, Power.kicad_sch]
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2026-03-02 Change magnetometer interrupt pin from sensor input to output
    [Sensors.kicad_sch, XuLabController.kicad_sch]
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2026-03-02 Remove redundant USB data line series resistors and CM choke
    [Microcontroller.kicad_sch]
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2026-03-03 Fix connector capacitor alignment
    [XuLabController.kicad_pcb]
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2026-03-13 Add ideal diode to battery inputs using NCV68061
    [Batteries.kicad_sch, XuLabPower.kicad_sch]
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2026-03-20 Add TVS diodes to switch and converter outputs
    [Converters.kicad_sch, XuLabPower.kicad_sch]
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2026-03-21 Flip XT60 pin connections
    [Batteries.kicad_sch]
2026-03-21 Add capacitors to ideal diode inputs / outputs
    [Batteries.kicad_sch]
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2026-03-26 Add internal 5 and 3.3 V power layers
    [XuLabPower.kicad_pcb]
2026-03-26 Shorten board length
    [XuLabPower.kicad_pcb]
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
